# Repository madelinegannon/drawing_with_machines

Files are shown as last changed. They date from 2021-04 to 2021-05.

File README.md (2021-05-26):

# Drawing with Machines
Tools, Tips, &amp; Tricks for Robot Plotters

Try out scripts and plots from the [`/samples`](https://github.com/madelinegannon/drawing_with_machines/samples) directory.

Build your own modular, magnetic drawing easel using the plans in the  [`/axidraw-easel`](https://github.com/madelinegannon/drawing_with_machines/axidraw-easel) directory.

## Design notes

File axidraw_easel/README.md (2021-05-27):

# AxiDraw Easel
#### A modular, magnetic drawing easel for the AxiDraw V3/A3 robotic plotter

_Designed by [Madeline Gannon](https://github.com/madelinegannon) and [Chris Ference](https://github.com/chrisference), Summer 2021_



## Overview
This easel helps you plot drawings that are larger than the 11" x 17" plot area of the [AxiDraw V3/A3](https://shop.evilmadscientist.com/productsmenu/890). It features a grid system with magnetic clamps, fences, and addons that hold, align, and re-register your paper or machine as needed.

## Files
All the 2D & 3D files to make and modify this easel design are [here](https://github.com/madelinegannon/drawing_with_machines/blob/main/axidraw_easel/files) in this repo.

### 2D Files
- Layout for the Magnet Grid ([SVG](https://github.com/madelinegannon/drawing_with_machines/blob/main/axidraw_easel/files/layout_magnets.svg))
- Layout for the Drawing Grid ([SVG](https://github.com/madelinegannon/drawing_with_machines/blob/main/axidraw_easel/files/layout_grid.svg))
- Full Illustrator File ([AI](https://github.com/madelinegannon/drawing_with_machines/blob/main/axidraw_easel/files/layout_axidraw_easel.ai))

### 3D Files
These jigs work like alignment fences or clamps, depending on their orientation.

| AxiDraw Alignment Jigs | Corner Jig | Straight Jig |
| :---: | :---: | :---: |
|  |  |  |
| [jig_shoe_left.stl](https://github.com/madelinegannon/drawing_with_machines/blob/main/axidraw_easel/files/jig_shoe_left.stl), [jig_shoe_right.stl](https://github.com/madelinegannon/drawing_with_machines/blob/main/axidraw_easel/files/jig_shoe_right.stl) | [jig_corner.stl](https://github.com/madelinegannon/drawing_with_machines/blob/main/axidraw_easel/files/jig_corner.stl) | [jig_straight.stl](https://github.com/madelinegannon/drawing_with_machines/blob/main/axidraw_easel/files/jig_straight.stl) |

## Module
We use a 30mm grid as the base unit for each module. Extend as you see fit!



## Build Your Own

### Tools & Supplies
- 3D Printer
- min. 24 inch x 24 inch x 3/4 inch sheet material with smooth surfacce (e.g., MDF, finished plywood)
- Magnets: [7/16" x 1/8"](https://www.mcmaster.com/5862K157/) ... lots of them.
- Hand Drill
- Drill bits up to 1/2 inch
- Hot glue gun / glue adhesive
- A3 (or larger) Paper
- Blue tape

### Fabrication Instructions

1. Print your desired [mounts and jigs](https://github.com/madelinegannon/drawing_with_machines/blob/main/axidraw_easel/files/).

2. Use your AxiDraw to plot the magnet template onto an A3 sheets of paper. Tape them together into one large sheet. 

3. Tape this magnet template to the bottom side of your plywood. 
> NOTE: The template has been mirrored so it can be mounted below the plywood.

4. Use a 1/8" inch bit to predrill holes where there are + signs marked on the template. Work your way up to 1/2" inch holes being careful to not go through the plywood. Once this is done, check to make sure the magnets fit.

5. Use your hot glue gun to glue a magnet inside each hole. 
> TIP: Use another magnet on the other side of the plywood to _pull_ this magnet into its hole. Not only does this snap it into place, it also ensures the correct polarity of the magnets. 

6. Glue magnets inside the holes in each 3D printed jig.
> NOTE: Make sure the polarity of these are consistant with the ones placed into the board.

7. Once all of the magnets have been placed, it's time to mount the axidraw and jigs. The first one you will want to place is the Alignment Jig which will hold the AxiDraw's feet in place.

8. Once you are confident in the alignment of the machine, plot the gridded surface on top of the board. We've provided the Illustrator file if you want to customize the bed grid. 
> TIP: Use the Corner Jigs to ensure that the 0,0 position aligns with the inside corner. Also, a fine-tipped Sharpie worked best for us, but give it some time to dry.

9. That's it! Now, it's time to experiment with the machine.

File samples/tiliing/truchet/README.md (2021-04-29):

# Truchet Multi-Scale Sample

- Open `truchet_multiscale.3dm` in Rhino and `truchet_multiscale.gh` in Grasshopper 3D to create your own pattern
- Plot `truchet_multiscale_wandering.svg` directly with an AxiDraw V3/A3



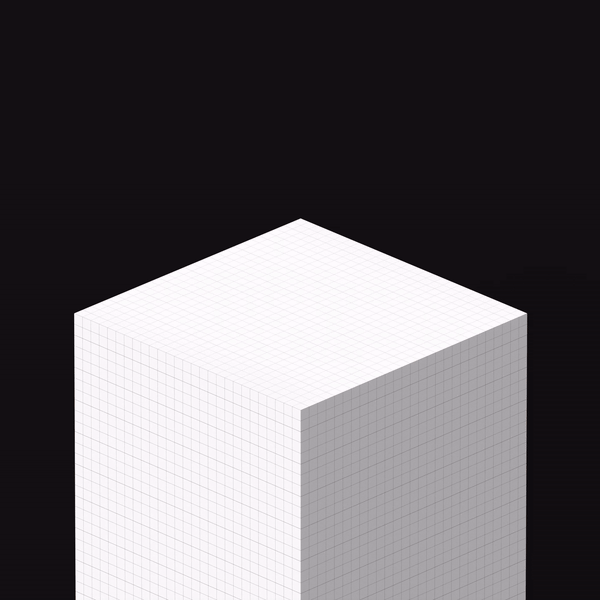
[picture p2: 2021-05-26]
axidraw_easel/images/hero_square.gif

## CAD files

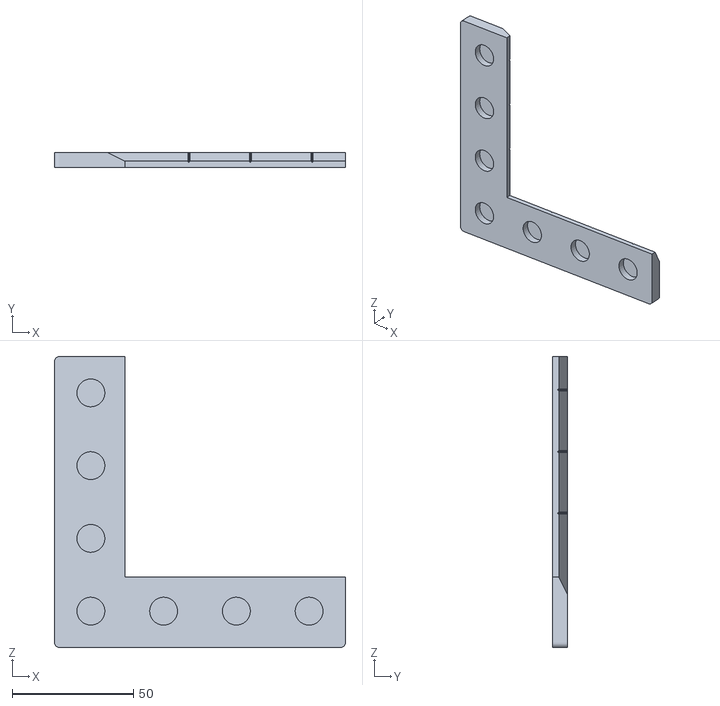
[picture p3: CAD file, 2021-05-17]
axidraw_easel/files/jig_corner.stl
120.0 x 6.00 x 120.0

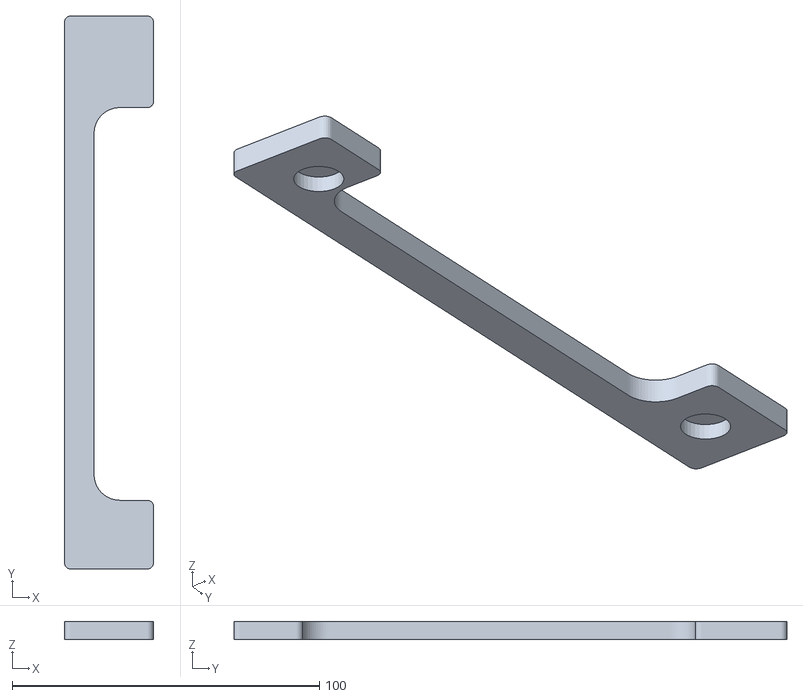
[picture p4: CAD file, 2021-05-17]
axidraw_easel/files/jig_shoe_left.stl
29.0 x 180.0 x 6.00

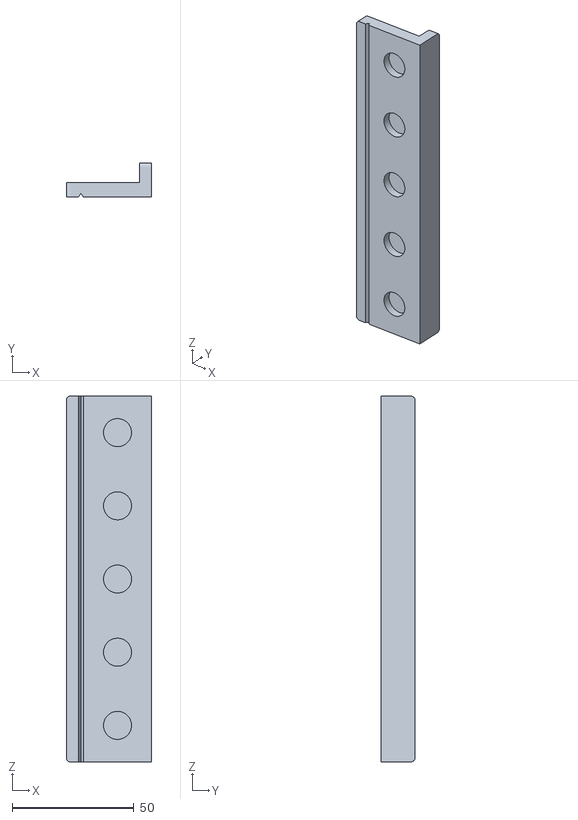
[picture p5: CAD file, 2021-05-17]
axidraw_easel/files/jig_straight.stl
35.0 x 14.0 x 150.0

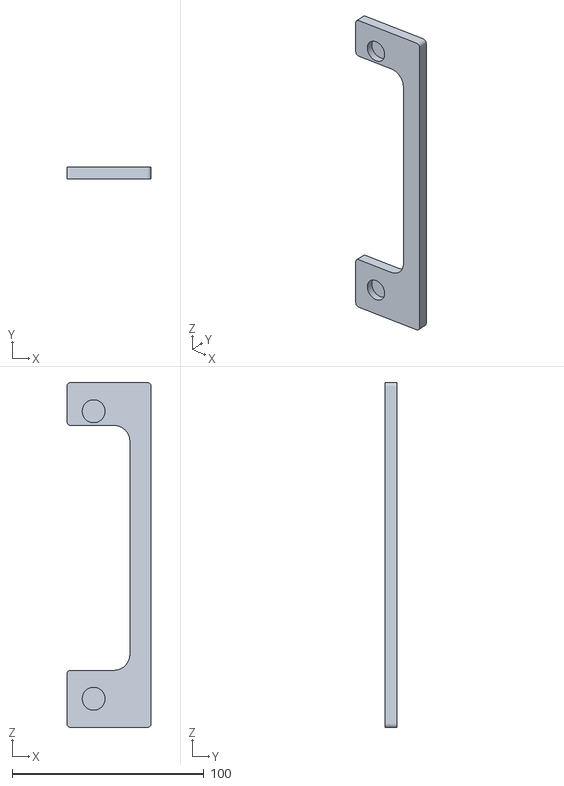
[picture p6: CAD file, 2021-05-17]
axidraw_easel/files/jig_shoe_right.stl
44.0 x 6.00 x 180.0

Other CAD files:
samples/tiliing/truchet/truchet_multiscale.3dm

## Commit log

2021-04-29 added truchet script and plots
    [truchet_multiscale.3dm]
2021-04-29 added random culling and compositing to gh script
    [truchet_multiscale.3dm]
2021-05-17 STL Files
    [Corner_Alignment_Jig.stl, Machine_Alignment_Jig_Left.stl, Machine_Alignment_Jig_Right.stl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]
2021-05-26 renamed files
    [Corner_Alignment_Jig.stl, Machine_Alignment_Jig_Left.stl, Machine_Alignment_Jig_Right.stl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]
